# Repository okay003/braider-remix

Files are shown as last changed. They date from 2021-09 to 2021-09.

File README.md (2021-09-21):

# braider-remix

DanFranCiscoさんのMaypole Braiding Machineを研究室の環境に合わせてリミックスしました。  
（DanFranCisco, Maypole Braiding Machine, https://cults3d.com/en/3d-model/gadget/maypole-braiding-machine, 20210922閲覧）

### 紹介
Braiding Machine (Braiderとも) は、ブレード（スリーブ）を編む機械です。  
ブレードはコードをまとめるネットなどに使われ、一部の3Dプリンタのコードはブレードでまとめられています。  

研究でブレードを作る必要が生じたためため、作成・改造を始めました。  

※ライセンスの都合でリミックスモデルは載せていません

https://user-images.githubusercontent.com/74394828/134202028-e461e6af-670c-4318-9b4b-2402353ed478.mp4

### 変更点
・駆動モータにDME44S6HPAを使用し、ギヤボックスを外しダイレクトドライブで駆動させた（3アンペア供給）  
・Braiderの駆動輪のギヤ比を減速モードに変更（推奨比（加速モード）を反転させる）  
・DME44S6HPAのダイレクトドライブかつ減速モード環境での編み角制御モデルを検討中  
・牽引ローラ（ステッピングモータと逆側）にバネを取り付けた  
・東京精機社製アルミフレームに固定するための先入れナットおよびスペーサ（jig）を作成した  
・ホコリよけにMDFボード製の覆いを作るためのフレームを作成した

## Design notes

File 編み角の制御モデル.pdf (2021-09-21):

編み角θを、単位時間あたりの引き込み長さlPと、単位時間あたりの編み長さlYを用いて図 1 のようにモデル化する。

θ = tan⁻¹

lP
lY

⋅⋅⋅ (∗)

引き込み長さlPについて、引き込みローラの径をDP、ローラの角速度をωPとしたとき、

lP = πDP ⋅

60
2π

ωP

= 30ωPDP ⋅⋅⋅ (∗∗)

また、駆動ギアのピッチ円の径をDd、ギアの角速度をωdとしたとき、本システムにおいてギア 数はn = 10である。隣接する2つのギアを1単位と定義したとき、すなわちシステムは 5 単位か ら構成される。単位あたりの摺動子の軌道長さtと、tだけ移動するのにかかる時間τは、

t =

144
360 πDd +

360 − 144
360 πDd

= πDd

τ =

144
360 πDd
ωd

+

360 − 144
360 πDd
ωd

=

πDd
ωd

すなわち、摺動子の総軌道長さTと、総移動時間Τは、
T = 5t
= 5πDd

Τ = 5τ

=

5πDd
ωd

よって、疑似編み角速度ωYは、

ωY =

T
Τ

=

5πDd
5πDd
ωd

= ωd

よって、編み長さlYについて、編み柱の径をDYとしたとき、

lY = πDY ⋅

60
2π

ωY

= 30ωYDY
= 30ωdDY ⋅⋅⋅ (∗∗∗)

以上、(∗∗), (∗∗∗)より、θは、次の通り与えられる。

θ = tan⁻¹

lP
lY

⋅⋅⋅ (∗)

= tan⁻¹

30ωPDP
30ωdDY

= tan⁻¹

ωPDP
ωdDY

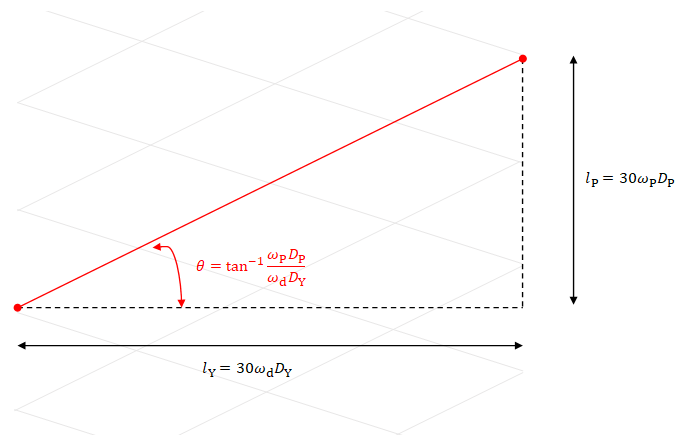
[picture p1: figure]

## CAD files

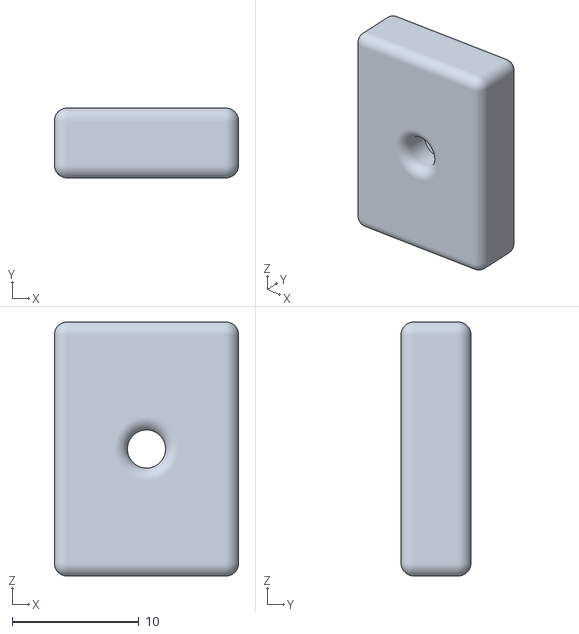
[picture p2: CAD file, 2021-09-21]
jig/braider jig/braider holder v1.stl
14.5 x 5.50 x 20.0

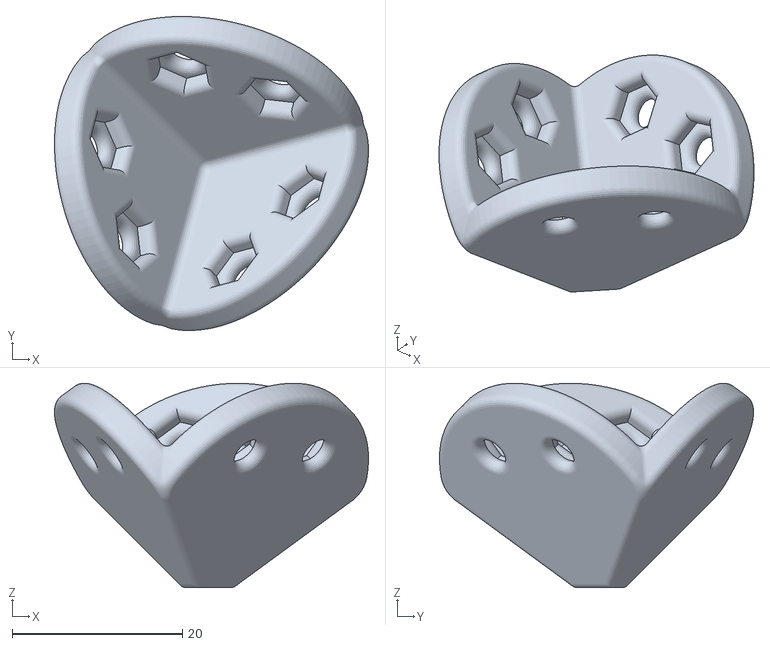
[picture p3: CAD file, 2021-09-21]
jig/cover/box top inner.stl
36.9 x 36.9 x 24.0

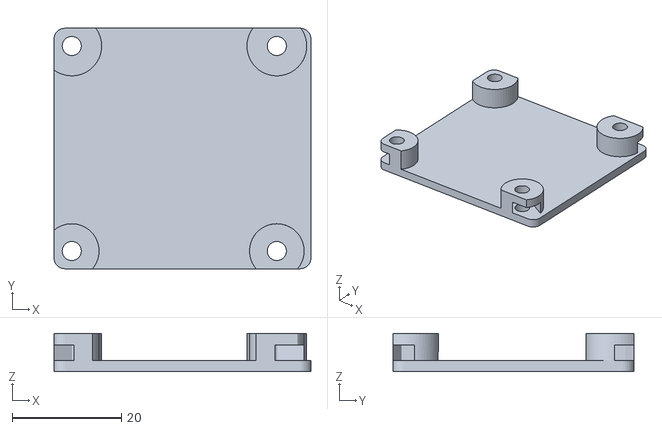
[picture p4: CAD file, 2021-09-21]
jig/L298N jig.stl
47.0 x 44.0 x 7.00

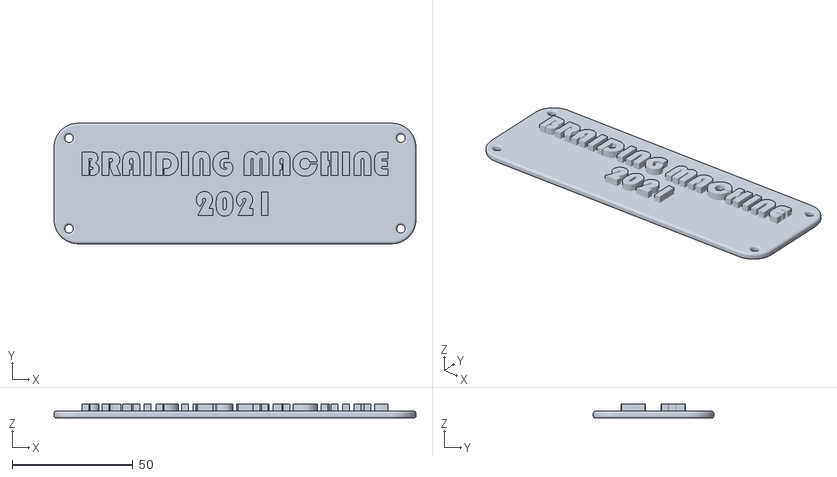
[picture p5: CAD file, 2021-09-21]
nameplate.stl
150.0 x 50.0 x 6.00

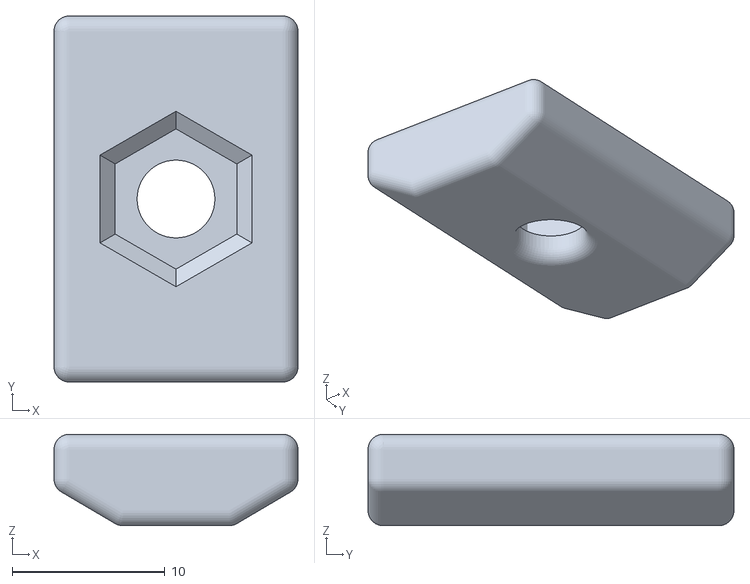
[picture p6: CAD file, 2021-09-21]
jig/braider jig/frame holder v4.stl
16.0 x 24.0 x 6.00

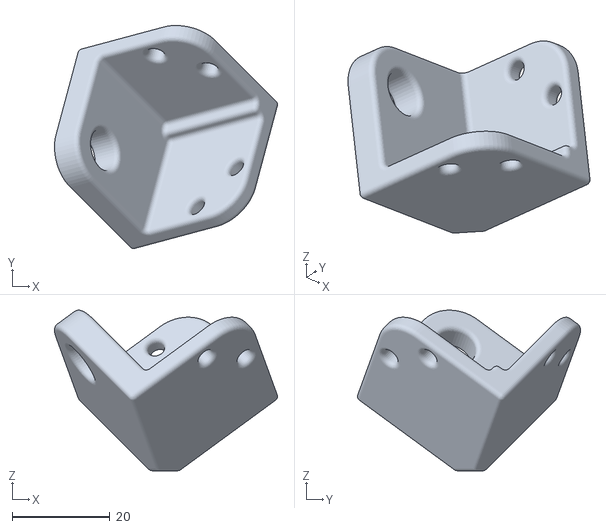
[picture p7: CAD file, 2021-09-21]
jig/cover/box bottom outer.stl
45.7 x 45.7 x 32.9

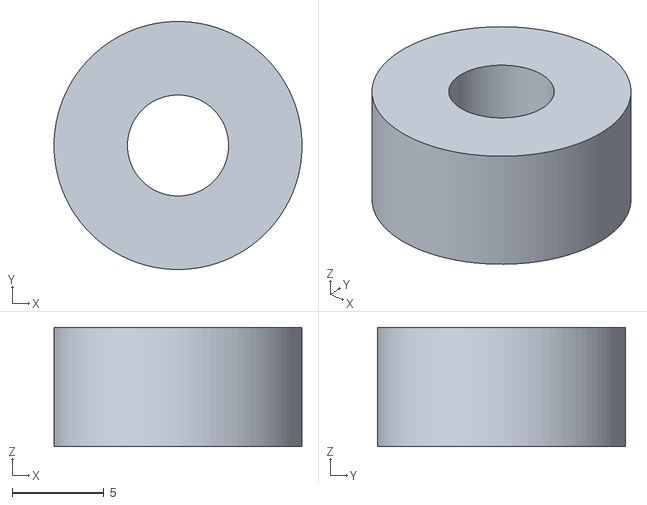
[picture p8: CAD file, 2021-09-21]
jig/braider jig/frame spacer v1.stl
13.5 x 13.5 x 6.50

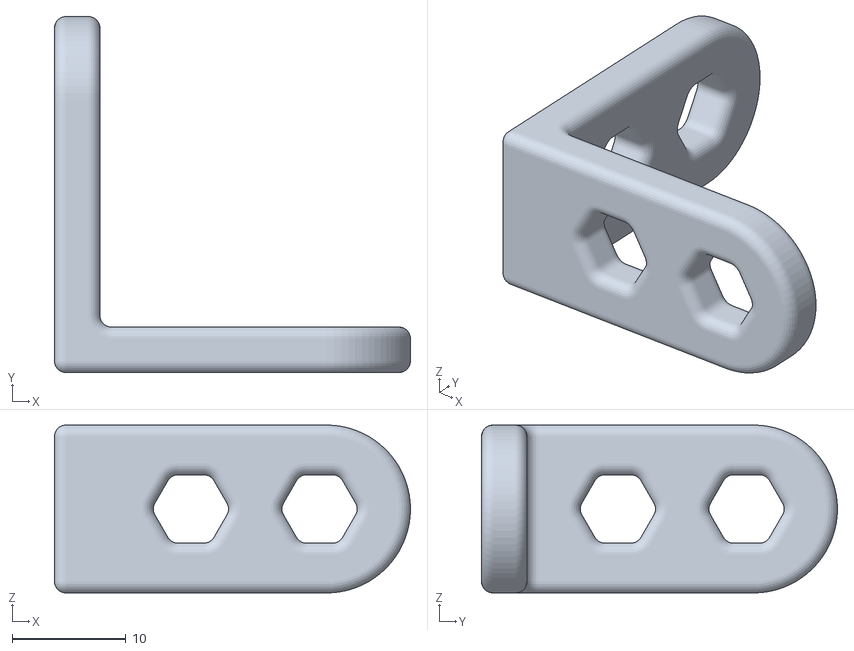
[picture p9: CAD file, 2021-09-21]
jig/cover/box edge inner.stl
31.3 x 31.3 x 14.8

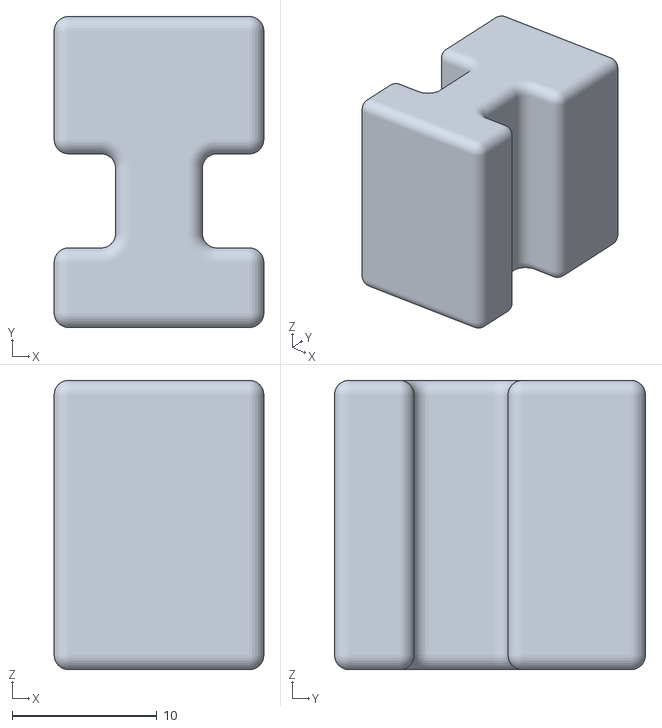
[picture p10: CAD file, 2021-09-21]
jig/braider jig/gearbox spacer v4.stl
14.5 x 21.5 x 20.0

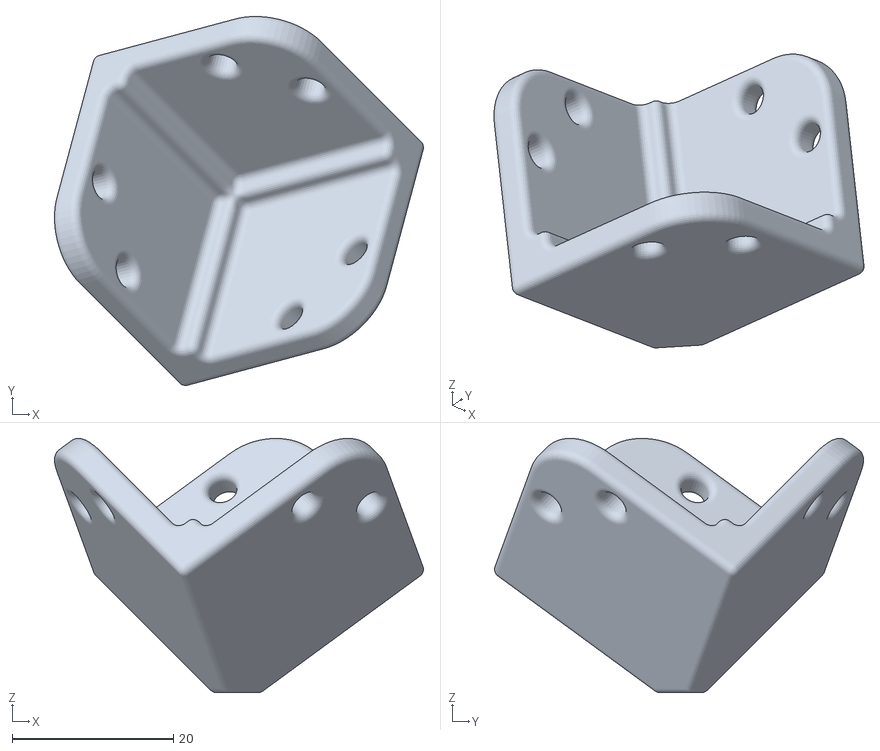
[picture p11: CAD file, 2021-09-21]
jig/cover/box top outer.stl
45.7 x 45.7 x 31.5

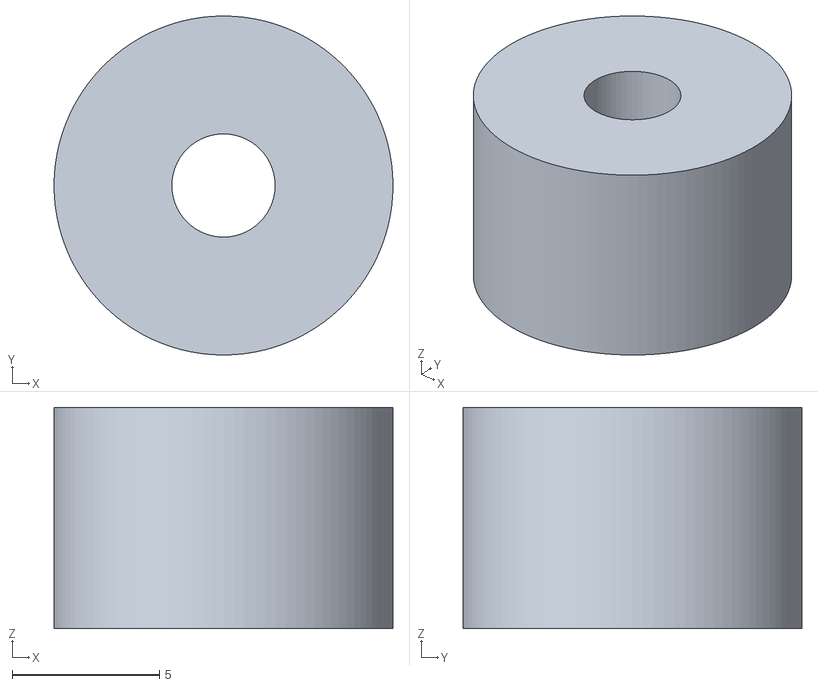
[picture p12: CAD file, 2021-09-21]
jig/braider jig/braider spacer v1.stl
11.5 x 11.5 x 7.50

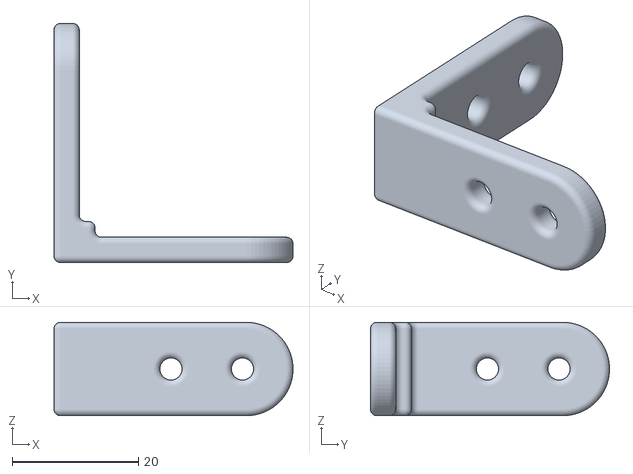
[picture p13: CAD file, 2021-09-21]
jig/cover/box edge outer.stl
37.8 x 37.8 x 14.8

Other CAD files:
jig/cover/box bottom inner.stl

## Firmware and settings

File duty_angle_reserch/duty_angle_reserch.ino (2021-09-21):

// see this site (step) :
// see this site (dc) : https://aisumegane.com/l298n/

#include <AccelStepper.h>

#define STEP_IN1 4
#define STEP_IN2 5
#define STEP_IN3 6
#define STEP_IN4 7
#define STEP_INTERFACE 8
#define DC_IN1 9
#define DC_IN2 8
#define DC_PWM 10

AccelStepper stepper(STEP_INTERFACE, STEP_IN1, STEP_IN3, STEP_IN2, STEP_IN4);

bool isOneShot=false;

int driveSpeed = 0;
int pullSpeed = 1000;

void setup() {
  Serial.begin(9600);
  stepper.setMaxSpeed(1000);
  pinMode(DC_IN1, OUTPUT);
  pinMode(DC_IN2, OUTPUT);
  pinMode(DC_PWM, OUTPUT);
}

void runStepper() {
  stepper.setSpeed(pullSpeed);
  stepper.runSpeed();
}

void runDC(long speed) {
  digitalWrite(DC_IN1, HIGH);
  digitalWrite(DC_IN2, LOW);
  analogWrite(DC_PWM, speed);
}

int serialGetDuty() {
  if (Serial.available() > 0) {
    long value = Serial.readString().toInt();
    if (value < 0) {
      value = 0;
    } else if (value > 255) {
      value = 255;
    }
    Serial.println(value);
    return (int)value;
  }
}

void loop() {
  runStepper();
  driveSpeed = serialGetDuty();
  runDC(driveSpeed);
}
